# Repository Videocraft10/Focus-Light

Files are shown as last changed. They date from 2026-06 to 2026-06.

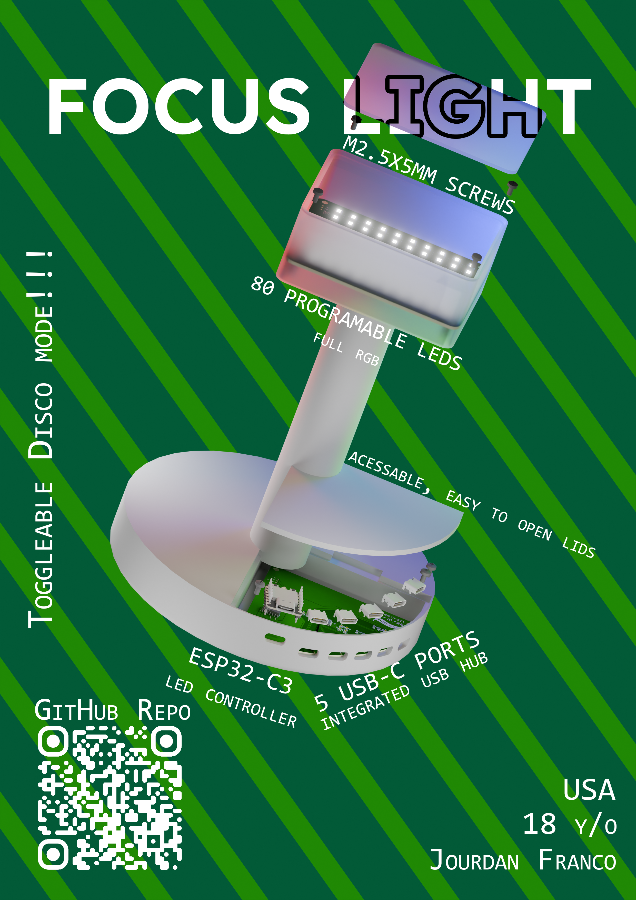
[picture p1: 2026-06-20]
Promo Files/Exports/Videocraft Focus Light Zine.png

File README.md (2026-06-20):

# Focus-Light
Custom Made Desk Light

## Features
Videocraft Focus Light Zine

1. Smooth light dimming
2. Approx. 400 to 500 lumens of brightness
3. Buttons to control lights
4. Disco Mode!!
5. INFINITE CUSTOMIZABILITY DUE TO WLED FIRMWARE

## Why?

I wanted to create an incredibly useful project that I would use basically every single day that could live on my desk at home. Additionally, this project will help me fully understand how lights work and how electronics can be integrated into daily life.

## The PCB

The PCB for this project was created within EasyEDA for easy parts and footprint integration.

### The Schematic



### The PCB

*USB Hub and Chip Section*

**Front**



**Back**



**3D**



*LED Section*

**Front**



**Back**



**3D**



## The Case
Full case



Easy-to-open lids to access PCBs




Hollow tube in the middle to be able to thread wires between the two PCBs


## Firmware

I decided to use WLED to control the lights! A guide on how to install this on your own project can be found [here](https://kno.wled.ge/basics/getting-started/).

## BOM
*Cost is for TWO PCBs (minimum amount for PCBA)*

| Item | LCSC # / Item Links | Single Cost | Amount Used | Fees/Notes | Total Price |
| --- | --- | --- | --- | --- | --- |
| 1uF Capacitor | [C15849](https://www.lcsc.com/product-detail/C15849.html?s_z=n_q_C15849&globalKeyword=C15849) | $0.0148 | 16 | ---------- | $0.2368 |
| 100nF Capacitor | [C14663](https://www.lcsc.com/product-detail/C14663.html?s_z=n_q_C14663&globalKeyword=C14663) | $0.0094 | 6 | ---------- | $0.0564 |
| 56k Resistor | [C23206](https://www.lcsc.com/product-detail/C23206.html?s_z=n_q_C23206&globalKeyword=C23206) | $0.0020 | 16 | ---------- | $0.032 |
| 5.1k Resistor | [C23186](https://www.lcsc.com/product-detail/C23186.html?s_z=n_q_C23186&globalKeyword=C23186) | $0.0018 | 4 | ---------- | $0.0072 |
| 330 Resistor | [C23138](https://www.lcsc.com/product-detail/C23138.html?s_z=n_q_C23138&globalKeyword=C23138) | $0.0016 | 2 | ---------- | $0.0032 |
| **OPSCO Optoelectronics SK6812MINIRGBW-NW-P6** | [C7423107](https://www.lcsc.com/product-detail/C7423107.html?s_z=n_q_C7423107&globalKeyword=C7423107) | $0.1301 | 160 (80 per) | Forced to buy 162 | [...] |
| **CoreChips SL2.1s** | [C2684433](https://www.lcsc.com/product-detail/C2684433.html?s_z=n_q_C2684433&globalKeyword=C2684433) | $0.2494 | 2 | Forced to buy 5 | $1.247 |
| **TI SN74AHCT125DR** | [C155176](https://www.lcsc.com/product-detail/C155176.html?s_z=n_q_C155176&globalKeyword=C155176) | $0.3489 | 2 | ---------- | $0.6978 |
| **SHOU HAN TYPE-C16PIN** | [C393939](https://www.lcsc.com/product-detail/C393939.html?s_z=n_q_C393939&globalKeyword=C393939) | $0.0653 | 10 | ---------- | $0.6530 |
| ***Seeed Studio XIAO-ESP32 C3 DIP*** | [AliExpress](https://www.aliexpress.us/item/3256805951491414.html?channel=twinner ) | $8.48 | 2 | Excluding shipping and AliExpress fees | $16.96 |
|  |  |  |  |  |  |
| Part Total: | ---------- | ---------- | ---------- | ---------- | $34.1818 |
|  |  |  |  |  |  |
| ***Additional Fees*** | ---------- | ---------- | ---------- | ---------- | ---------- |
| PCB Price | ---------- | ---------- | ---------- | ---------- | $6 ($2 coupon, $8 normally) |
|  |  |  |  |  |  |
| **PCBA Price** | (Is for both PCBs. Chip part and LED part) | ---------- | ---------- | ---------- | **$35.52** |
| ---------- | Setup Fee | ---------- | ---------- | $16.36 | |
| ---------- | Stencil | ---------- | ---------- |  $3.06  | |
| ---------- | Extended Components fee (boldfaced components) | ---------- | ---------- | $12.28 |  |
| ---------- | SMT Assembly | ---------- | ---------- | $2.12 |  |
| ---------- | Nitrogen Reflow Soldering | ---------- | ---------- | $1.70 |  |
|  |  |  |  |  |  |
| Shipping Fees | ---------- | ---------- | ---------- | ---------- | $22.60 |
| Sales Tax | ---------- | ---------- | ---------- | ---------- | $6 |
|  |  |  |  |  |  |
| ***GRAND TOTAL (for 2)*** | ---------- | ---------- | ---------- | ---------- | $104.3018 (gah dam) |

## How to use!
### LEDs

Simply plug the lamp in! The LEDs will turn on automatically or according to your own WLED setup. Ensure you are plugging into the non-USB hub ports (the 5 lower ports).

### USB Hub

Simply plug your computer into the lower USB port closest to the raised one, and plug any accessories into the other lower ones to the right.

## How to Build

Download the EasyEDA file from [here](https://github.com/Videocraft10/Focus-Light/blob/main/PCB%20Files/ProPrj_Videocraft%20Focus%20Light.epro2) and upload it to EasyEDA's PCB fabrication service.  
Click PCBA, and select how many you want assembled (minimum 2).  
Then download all case files from [here](https://github.com/Videocraft10/Focus-Light/tree/main/CAD%20Files/Case) or [here for 3D print-ready files](https://github.com/Videocraft10/Focus-Light/tree/main/CAD%20Files/Case/STL).  
Slice the files in your slicer of choice and 3D print each part. Please note that this is quite large, so you need a printer with a spacious print bed.  
Screw in the PCBs and solder on the ESP-32C3 and wires on the chip PCB to the LED PCB.  
Plug the lamp into your computer through the raised USB port and install WLED [https://install.wled.me/](https://install.wled.me/).  
Once installed, follow the in-depth instructions on the WLED website to connect your lamp to a controller device like your phone or through the web.  
You can control effects and color through there!

Optional! You can create your own custom firmware for the ESP32 to make the LEDs do anything you want, or use WLED like I did.

## Software Used

Blender  
EasyEDA  
Fusion  
Adobe Photoshop

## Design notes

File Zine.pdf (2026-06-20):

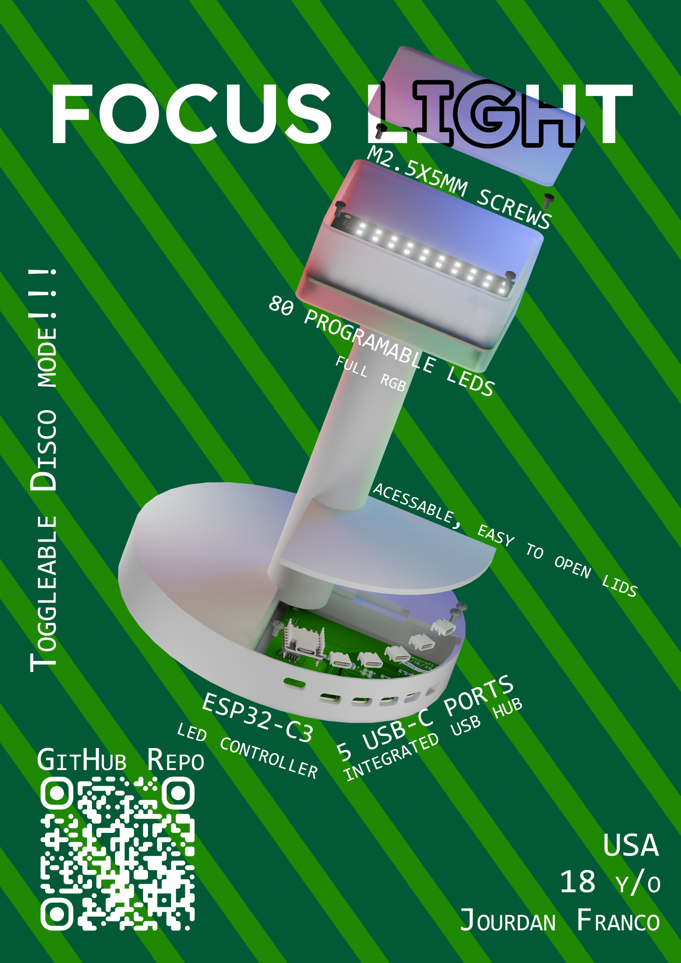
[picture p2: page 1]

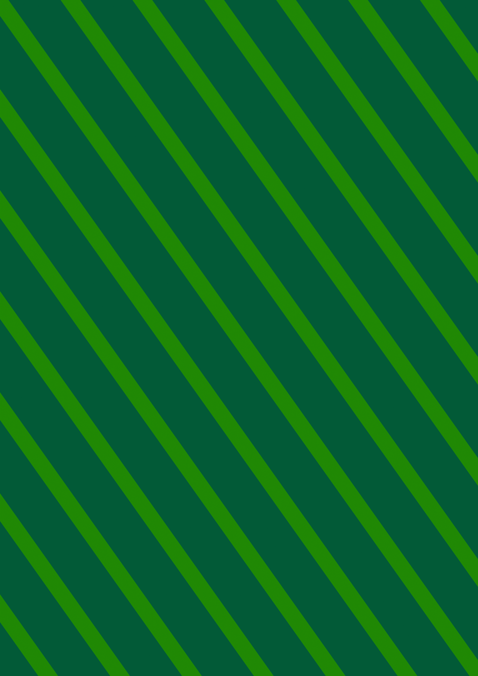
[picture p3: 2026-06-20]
Promo Files/Exports/Zine Background.png

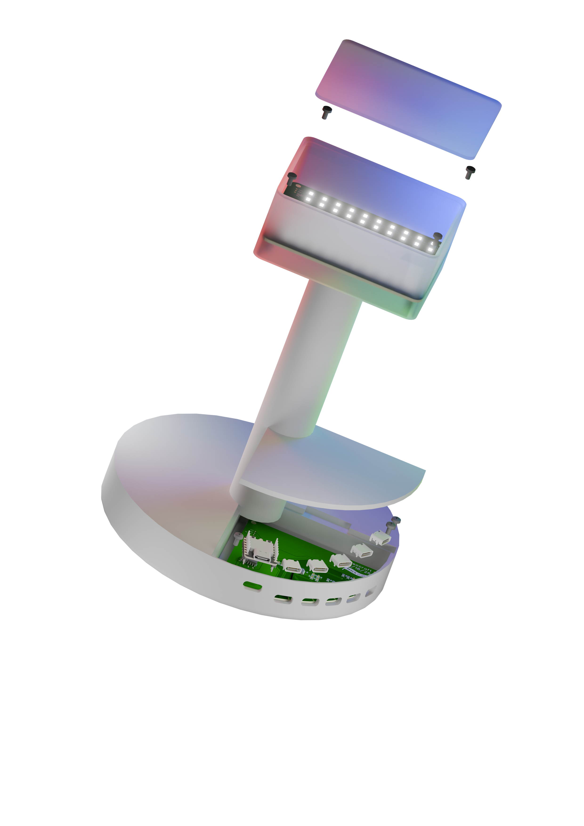
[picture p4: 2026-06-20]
Promo Files/Exports/Zine Transparent.png

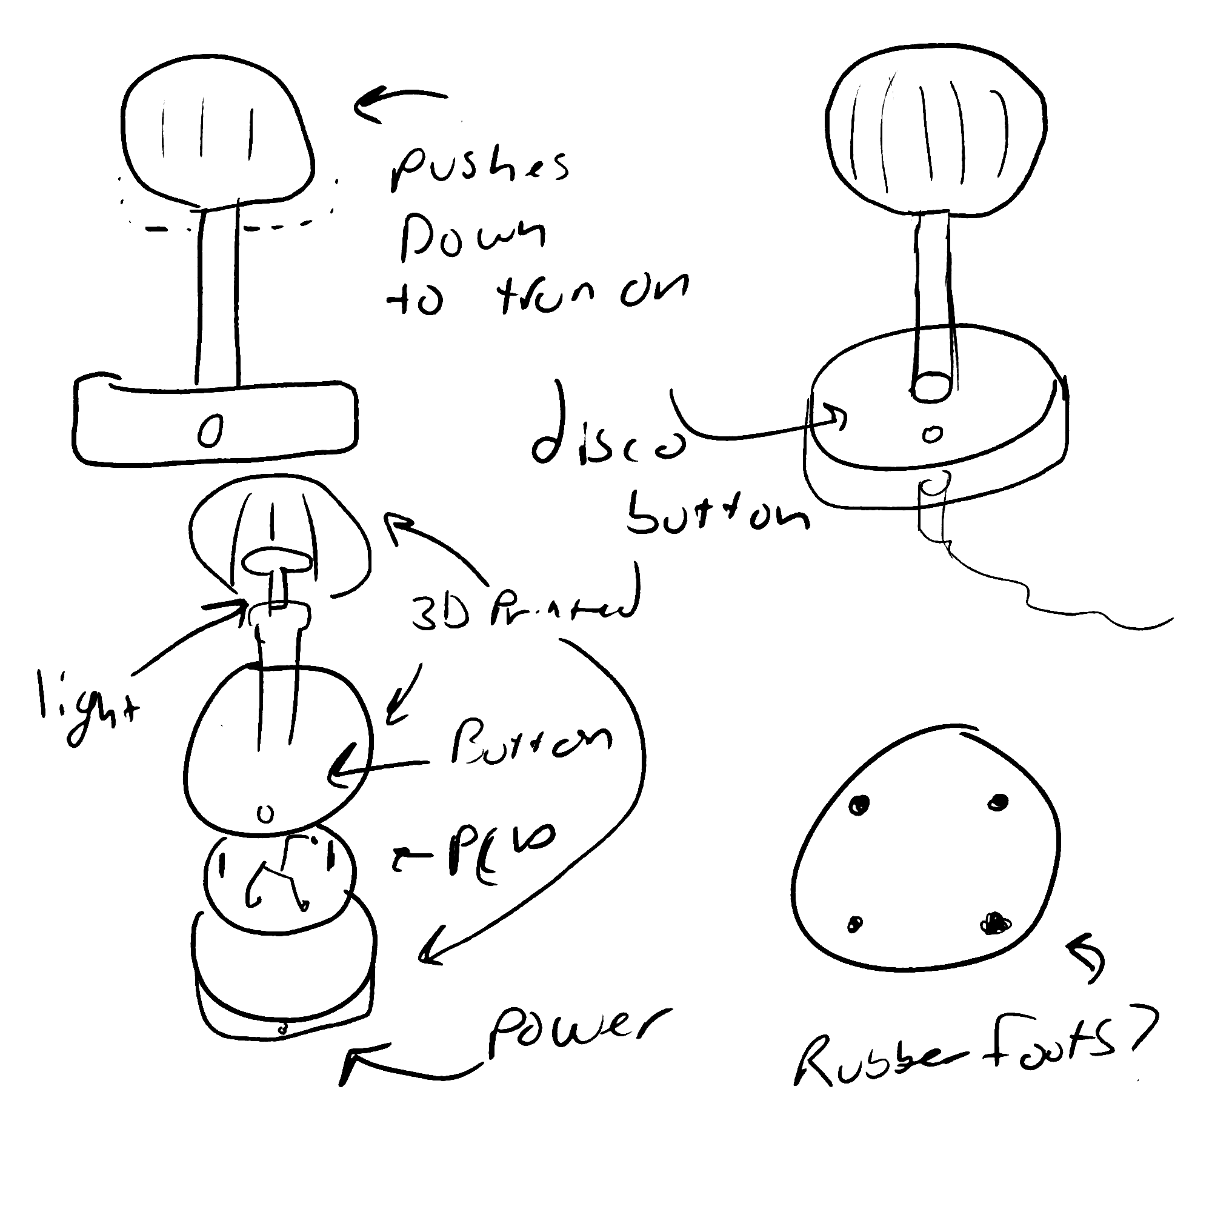
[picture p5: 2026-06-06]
Promo Files/Mockup/Focus Lamp Mock.png

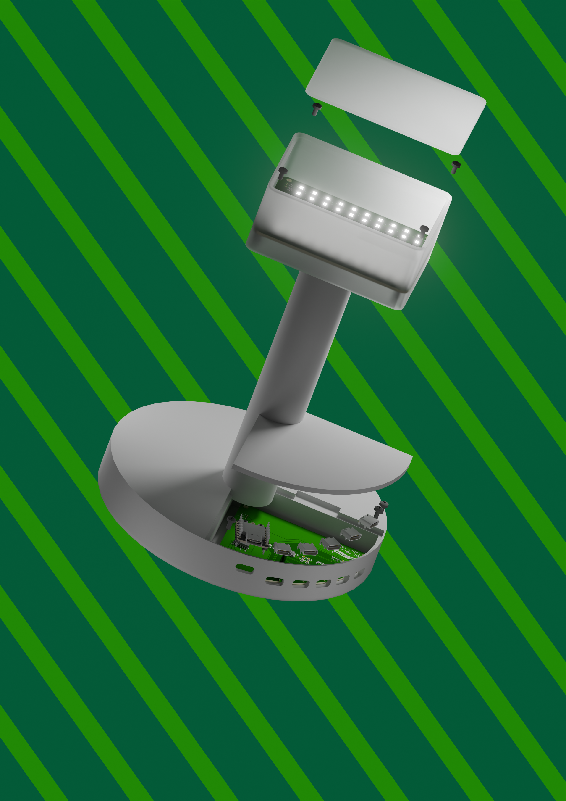
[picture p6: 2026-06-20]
Promo Files/Exports/Zine Full.png

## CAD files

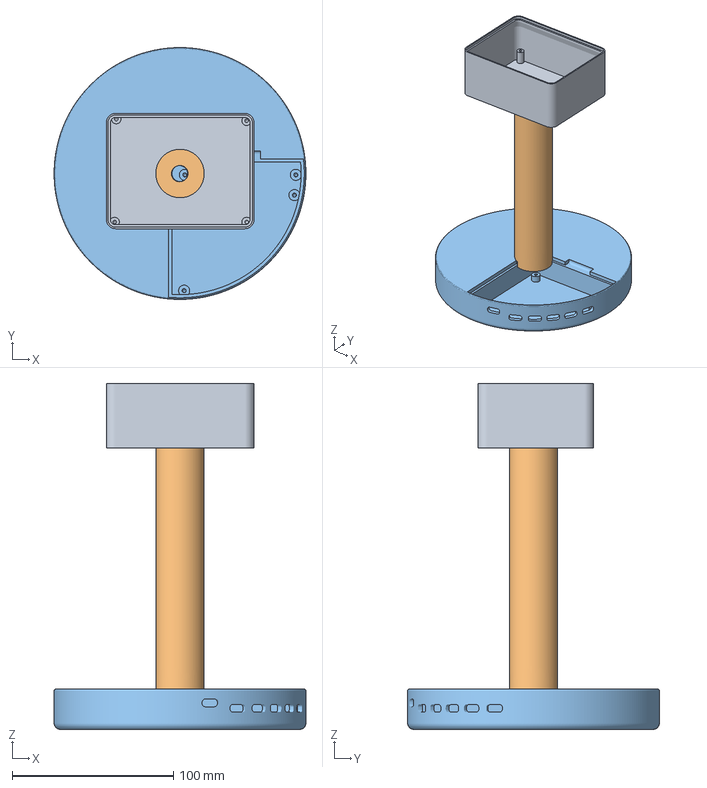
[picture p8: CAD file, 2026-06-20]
3D Print Files/MainBody.3mf
156.0 x 156.0 x 214.3 mm

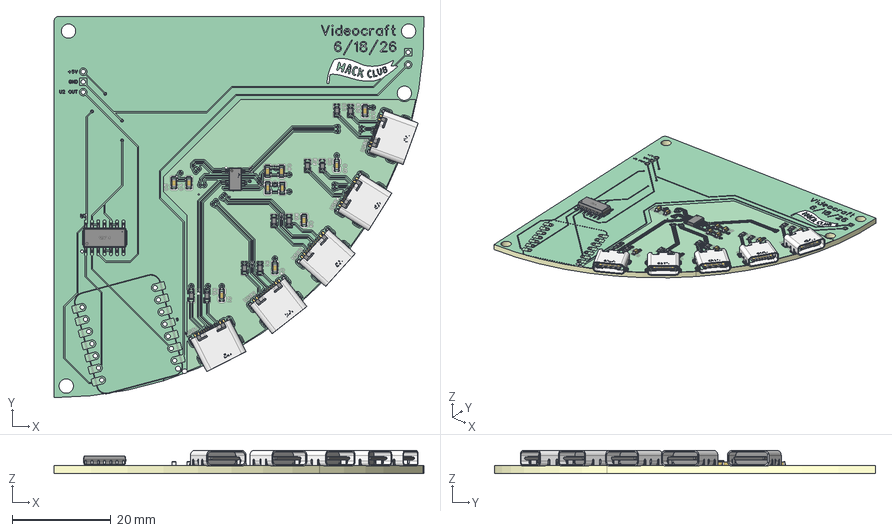
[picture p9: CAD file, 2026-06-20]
CAD Files/PCBs/3D_PCBChip.step
74.8 x 77.1 x 4.71 mm
Board~jWBP
TopCopper~jWBP x 97
BottomCopper~jWBP x 31
TopSilkscreen~jWBP x 177
BottomSilkscreen~jWBP
TopFpcStiffener~jWBP
BottomFpcStiffener~jWBP
R0603~R0603~jWBP x 10
C0603~C0603_L1.6-W0.8-H0.8~jWBP x 11
USB-C-SMD_TYPE-C16PIN~USB-C-SMD_TYPE-C16PIN~jWBP x 5
SOIC-14_L8.7-W3.9-P1.27-LS6.0-BL~SOIC-14_ L8.6-W3.9-H1.8-LS6.0-P1.27~jWBP
SSOP-16_L4.6-W2.6-P0.53-LS4.0-BL~SSOP-16_L4.6-W2.6-P0.53-LS4.0-BL~jWBP

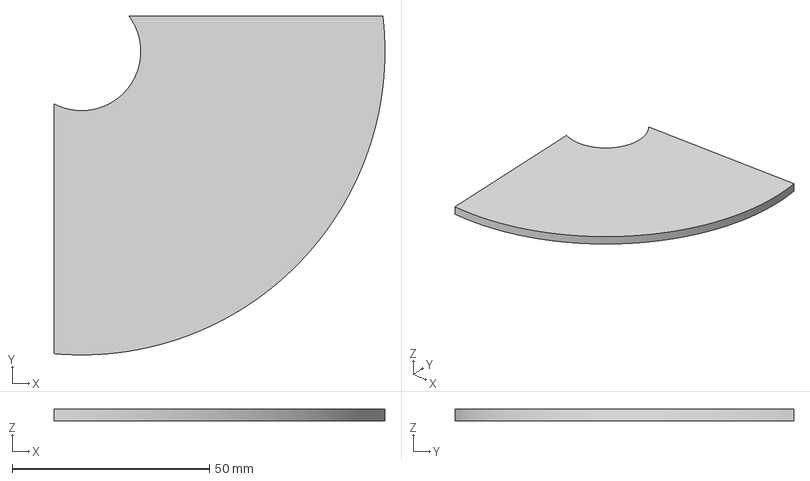
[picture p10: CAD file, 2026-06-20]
3D Print Files/RingLid.3mf
84.0 x 86.0 x 3.00 mm

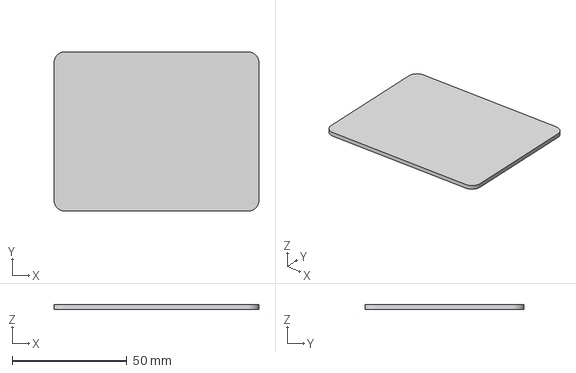
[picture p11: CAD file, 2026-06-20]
3D Print Files/LEDLid.3mf
89.5 x 69.5 x 2.00 mm

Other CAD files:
Promo Files/Focus Light Zine.blend

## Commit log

2026-06-06 Added KiCAD project files, and mockup images
    [Focus Light PCB.kicad_pcb, Focus Light PCB.kicad_sch]
2026-06-07 Small progress on kicad file due to switching over to easyeda
    (KiCad folder will be deleted soon)
    [Focus Light PCB.kicad_pcb, Focus Light PCB.kicad_sch]
2026-06-12 Update PCB file
2026-06-15 Enhance README with PCB details and images
    Added detailed sections for PCB schematic and components with images.
2026-06-16 Update README with BOM details
    Added BOM table with component costs and links.
2026-06-16 Added final PCB easyeda files, .step files and gerber files
    [3D_PCBChip.step]
2026-06-17 Add links to component items in the BOM
2026-06-20 CASE AND ZINE DONE
    [3D_PCBChip.step, Focus Light Zine.blend, LEDLid.3mf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]
